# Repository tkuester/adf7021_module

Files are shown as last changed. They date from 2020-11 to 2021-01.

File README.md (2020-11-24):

# ADF7021 Module

Per a discussion with SP5WWP, it would be advantageous to the M17 project to
have a breakout board that can be uesd to prototype with the AD7021 module.
While Analog provides a reasonably priced development module, it is difficult
to modify, and doesn't integrate well into other projects.

Given this, the module should be...

 - Hackable
   - Easy to use as a standalone board (ie: 0.1" headers)
   - Assemble with hobbyist level equipment
   - Financially accessable, limit difficult to source parts
 - Modular
   - Minimize commitments like filter topology / amplifier output
     - Can use as TX, RX, or TX/RX (two SMA conns)
   - Optional footprints to allow for various configurations
 - Designed to integrate into later projects
   - RF shileding footprint
   - Mounting holes, pluggable connectors, etc
 - Not designed for the TR-9
   - Suspect TR-9 needs tighter integration
   - Would be nice, but requirements seem to conflict

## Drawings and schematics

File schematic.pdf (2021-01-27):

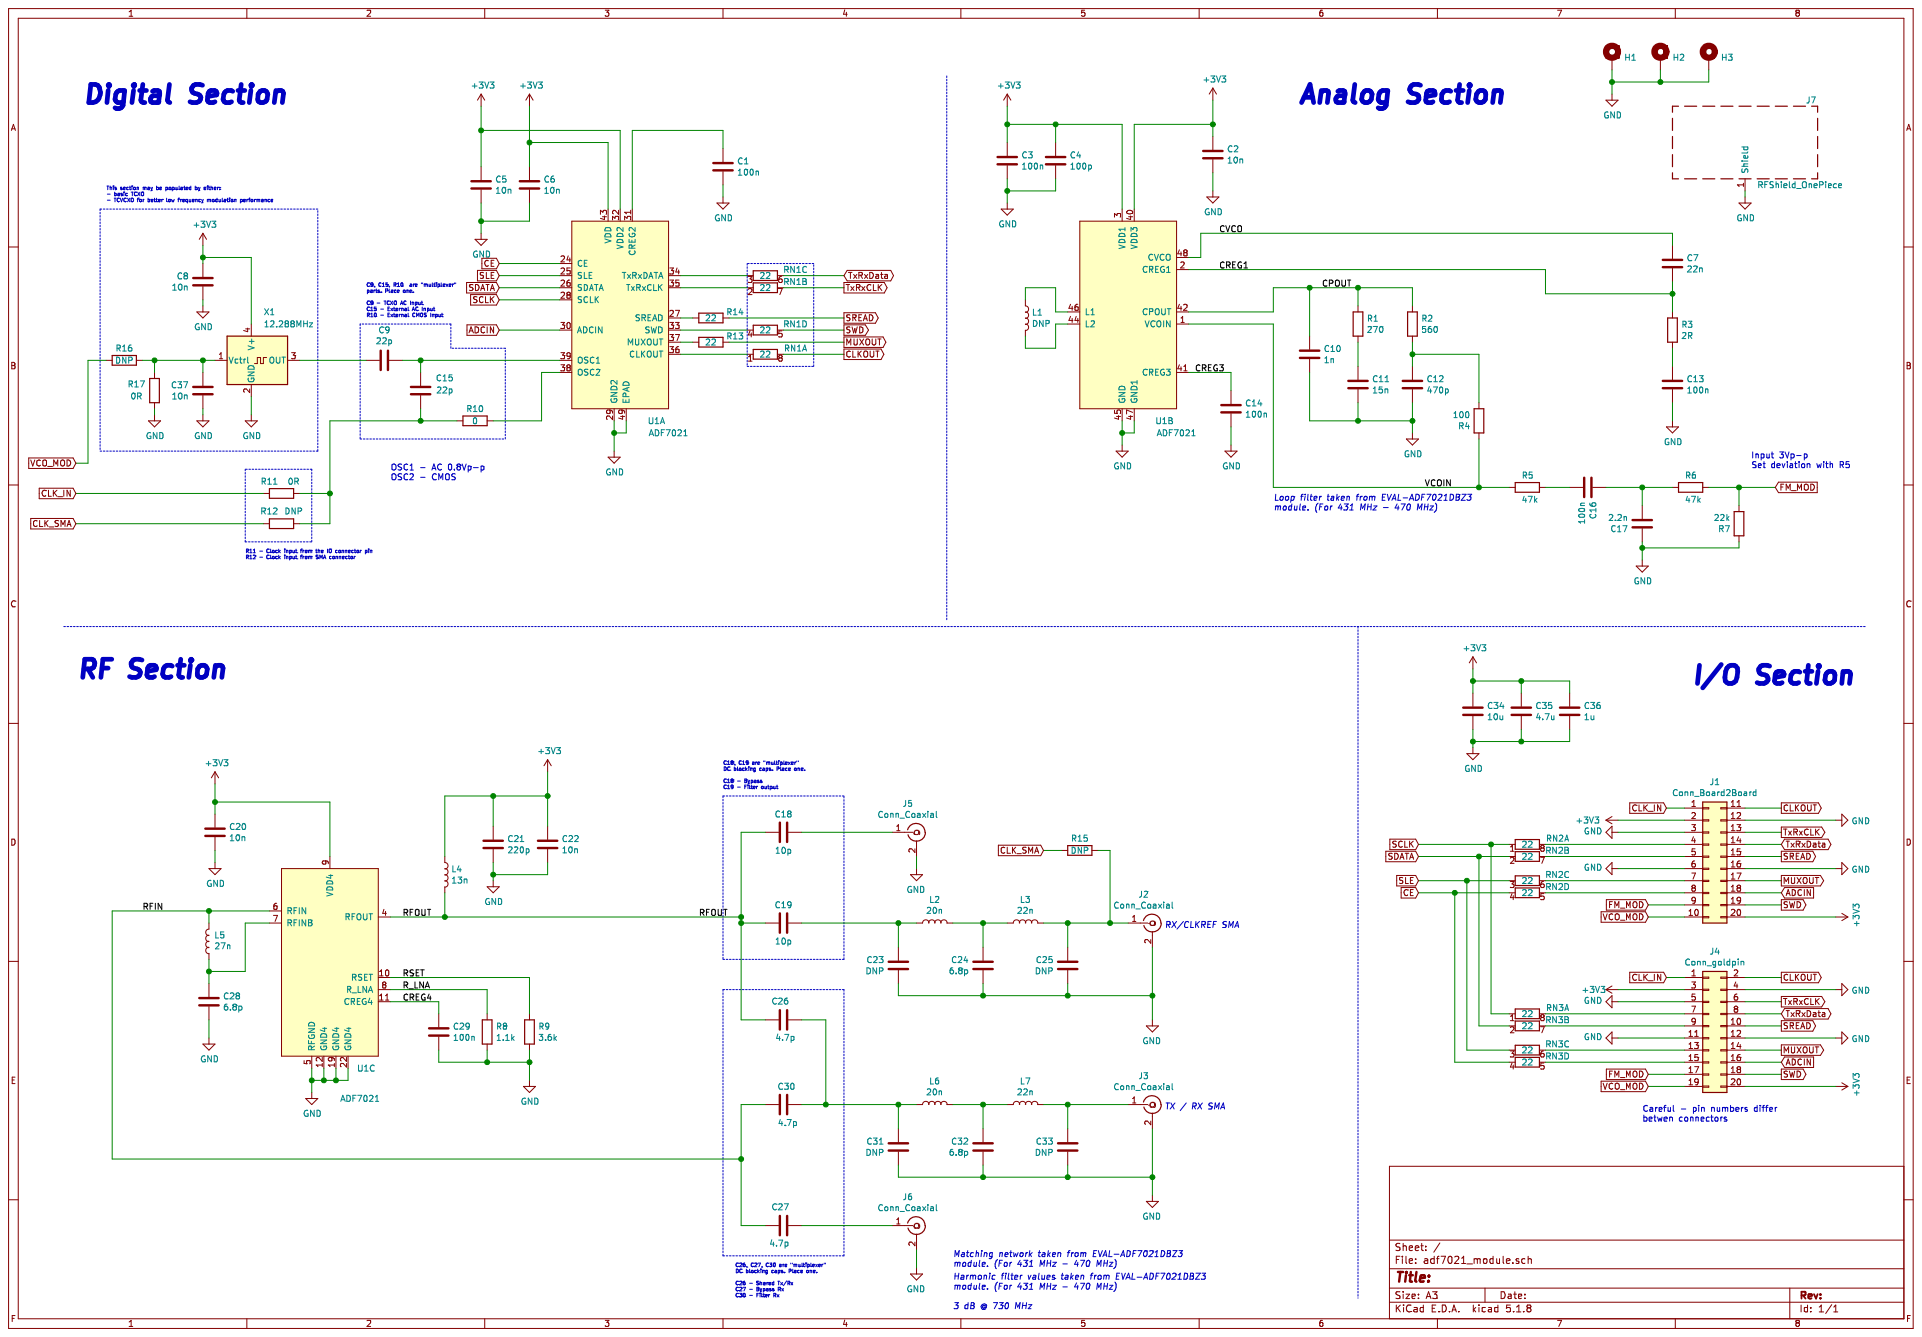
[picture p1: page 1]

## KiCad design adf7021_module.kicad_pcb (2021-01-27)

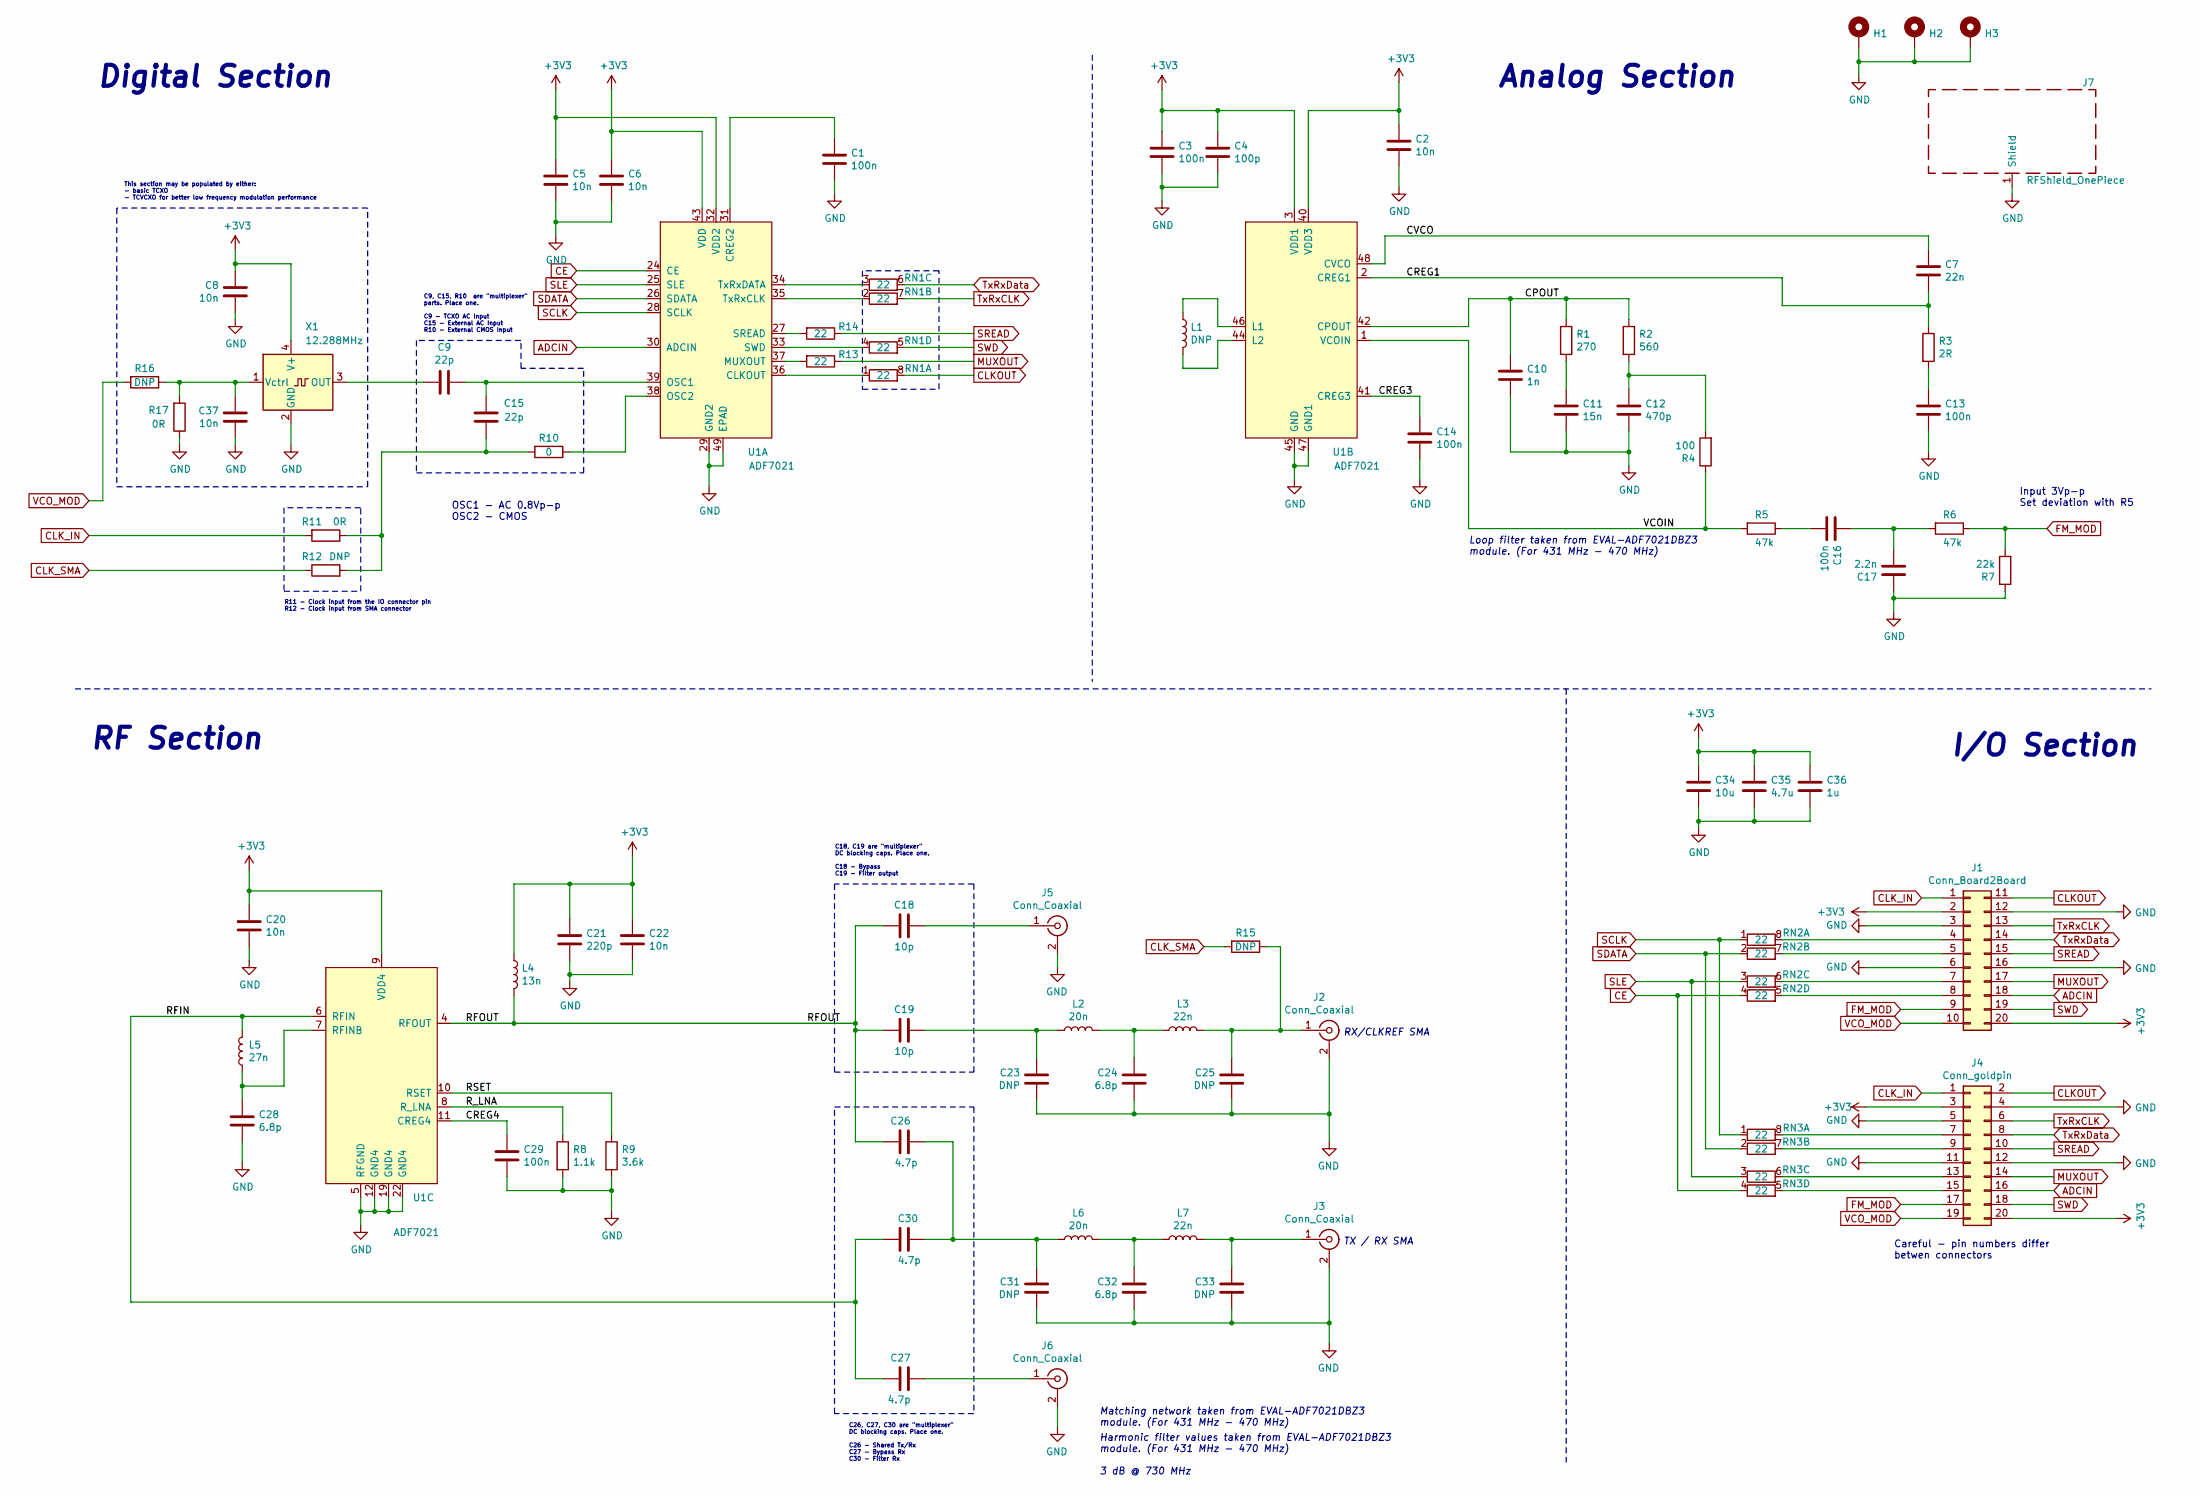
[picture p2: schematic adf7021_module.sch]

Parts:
C1, C3, C13, C14, C16, C29: 100n; C_0402_1005Metric_Pad0.74x0.62mm_HandSolder
C2, C5, C6, C8, C20, C22, C37: 10n; C_0402_1005Metric_Pad0.74x0.62mm_HandSolder
C4: 100p; C_0402_1005Metric_Pad0.74x0.62mm_HandSolder
C7: 22n; C_0402_1005Metric_Pad0.74x0.62mm_HandSolder
C9, C15: 22p; C_0402_1005Metric_Pad0.74x0.62mm_HandSolder
C10: 1n; C_0402_1005Metric_Pad0.74x0.62mm_HandSolder
C11: 15n; C_0402_1005Metric_Pad0.74x0.62mm_HandSolder
C12: 470p; C_0402_1005Metric_Pad0.74x0.62mm_HandSolder
C17: 2.2n; C_0402_1005Metric_Pad0.74x0.62mm_HandSolder
C18, C19: 10p; C_0402_1005Metric_Pad0.74x0.62mm_HandSolder
C21: 220p; C_0402_1005Metric_Pad0.74x0.62mm_HandSolder
C23, C25, C31, C33: DNP; C_0402_1005Metric_Pad0.74x0.62mm_HandSolder
C24, C28, C32: 6.8p; C_0402_1005Metric_Pad0.74x0.62mm_HandSolder
C26, C27, C30: 4.7p; C_0402_1005Metric_Pad0.74x0.62mm_HandSolder
C34: 10u; C_0603_1608Metric_Pad1.08x0.95mm_HandSolder
C35: 4.7u; C_0603_1608Metric_Pad1.08x0.95mm_HandSolder
C36: 1u; C_0603_1608Metric_Pad1.08x0.95mm_HandSolder
H1, H2, H3: MountingHole_Pad; MountingHole_2.2mm_M2_Pad_TopBottom
J1: Conn_Board2Board; Hirose_DF12_DF12E3.0-20DP-0.5V_2x10_P0.50mm_Vertical
J2, J3: Conn_Coaxial; SMA_Molex_73251-2200_Horizontal
J4: Conn_goldpin; PinSocket_2x10_P2.54mm_Vertical
J5, J6: Conn_Coaxial; U.FL_Hirose_U.FL-R-SMT-1_Vertical
J7: RFShield_OnePiece; Laird_Technologies_BMI-S-205-F_38.10x25.40mm
L1: DNP; L_0402_1005Metric_Pad0.77x0.64mm_HandSolder
L2, L6: 20n; L_0402_1005Metric_Pad0.77x0.64mm_HandSolder
L3, L7: 22n; L_0402_1005Metric_Pad0.77x0.64mm_HandSolder
L4: 13n; L_0402_1005Metric_Pad0.77x0.64mm_HandSolder
L5: 27n; L_0402_1005Metric_Pad0.77x0.64mm_HandSolder
R1: 270; R_0402_1005Metric_Pad0.72x0.64mm_HandSolder
R2: 560; R_0402_1005Metric_Pad0.72x0.64mm_HandSolder
R3: 2R; R_0402_1005Metric_Pad0.72x0.64mm_HandSolder
R4: 100; R_0402_1005Metric_Pad0.72x0.64mm_HandSolder
R5, R6: 47k; R_0402_1005Metric_Pad0.72x0.64mm_HandSolder
R7: 22k; R_0402_1005Metric_Pad0.72x0.64mm_HandSolder
R8: 1.1k; R_0402_1005Metric_Pad0.72x0.64mm_HandSolder
R9: 3.6k; R_0402_1005Metric_Pad0.72x0.64mm_HandSolder
R10: 0; R_0402_1005Metric_Pad0.72x0.64mm_HandSolder
R11, R17: 0R; R_0402_1005Metric_Pad0.72x0.64mm_HandSolder
R12, R15, R16: DNP; R_0402_1005Metric_Pad0.72x0.64mm_HandSolder
R13, R14: 22; R_0402_1005Metric_Pad0.72x0.64mm_HandSolder
RN1, RN2, RN3: 22; R_Array_Concave_4x0402
U1: ADF7021; QFN-48-1EP_7x7mm_P0.5mm_EP5.3x5.3mm
X1: 12.288MHz; Oscillator_SMD_EuroQuartz_XO32-4Pin_3.2x2.5mm_HandSoldering

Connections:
+3V3: C2.1, C3.1, C4.1, C5.1, C6.1, C8.1, C20.1, C21.1, C22.1, C34.1, C35.1, C36.1, J1.2, J1.20, J4.3, J4.20, L4.1, U1.3 (VDD1), U1.9 (VDD4), U1.32 (VDD2), U1.40 (VDD3), U1.43 (VDD), X1.4 (V+)
/CPOUT: C10.1, R1.1, R2.1, U1.42 (CPOUT)
/CREG1: C7.2, R3.1, U1.2 (CREG1)
/CREG3: C14.1, U1.41 (CREG3)
/CREG4: C29.1, U1.11 (CREG4)
/CVCO: C7.1, U1.48 (CVCO)
/RFIN: C27.1, C30.2, L5.2, U1.6 (RFIN)
/RFOUT: C18.2, C19.2, C26.1, L4.2, U1.4 (RFOUT)
/RSET: R9.1, U1.10 (RSET)
/R_LNA: R8.1, U1.8 (R_LNA)
/VCOIN: R4.1, R5.2, U1.1 (VCOIN)
ADCIN: J1.18, J4.16, U1.30 (ADCIN)
CE: RN2.4 (R4.1), RN3.4 (R4.1), U1.24 (CE)
CLKOUT: J1.11, J4.2, RN1.8 (R1.2)
CLK_IN: J1.1, J4.1, R11.2
CLK_SMA: R12.1, R15.2
FM_MOD: J1.9, J4.17, R6.1, R7.2
GND: C1.2, C2.2, C3.2, C4.2, C5.2, C6.2, C8.2, C10.2, C11.2, C12.2, C13.2, C14.2, C17.1, C20.2, C21.2, C22.2, C23.2, C24.2, C25.2, C28.2, C29.2, C31.2, C32.2, C33.2, C34.2, C35.2, C36.2, C37.2, H1.1, H2.1, H3.1, J1.3, J1.6, J1.12, J1.16, J2.2 (Ext), J3.2 (Ext), J4.4, J4.5, J4.11, J4.12, J5.2 (Ext), J6.2 (Ext), J7.1, R7.1, R8.2, R9.2, R17.1, U1.5 (RFGND), U1.12 (GND4), U1.19 (GND4), U1.22 (GND4), U1.29 (GND2), U1.45 (GND), U1.47 (GND1), U1.49 (EPAD), X1.2 (GND)
MUXOUT: J1.17, J4.14, R13.1
unnamed: C1.1, U1.31 (CREG2)
unnamed: C9.2, X1.3 (OUT)
unnamed: C11.1, R1.2
unnamed: C12.1, R2.2, R4.2
unnamed: C13.1, R3.2
unnamed: C15.1, R10.2, R11.1, R12.2
unnamed: C9.1, C15.2, U1.39 (OSC1)
unnamed: C16.1, C17.2, R6.2
unnamed: C16.2, R5.1
unnamed: C18.1, J5.1 (In)
unnamed: C19.1, C23.1, L2.2
unnamed: C24.1, L2.1, L3.2
unnamed: C25.1, J2.1 (In), L3.1, R15.1
unnamed: C26.2, C30.1, C31.1, L6.2
unnamed: C27.2, J6.1 (In)
unnamed: C28.1, L5.1, U1.7 (RFINB)
unnamed: C32.1, L6.1, L7.2
unnamed: C33.1, J3.1 (In), L7.1
unnamed: C37.1, R16.1, R17.2, X1.1 (Vctrl)
unnamed: J1.4, RN2.8 (R1.2)
unnamed: J1.5, RN2.7 (R2.2)
unnamed: J1.7, RN2.6 (R3.2)
unnamed: J1.8, RN2.5 (R4.2)
unnamed: J4.7, RN3.8 (R1.2)
unnamed: J4.9, RN3.7 (R2.2)
unnamed: J4.13, RN3.6 (R3.2)
unnamed: J4.15, RN3.5 (R4.2)
unnamed: L1.1, U1.46 (L1)
unnamed: L1.2, U1.44 (L2)
unnamed: R10.1, U1.38 (OSC2)
unnamed: R13.2, U1.37 (MUXOUT)
unnamed: R14.2, U1.27 (SREAD)
unnamed: RN1.1 (R1.1), U1.36 (CLKOUT)
unnamed: RN1.2 (R2.1), U1.35 (TxRxCLK)
unnamed: RN1.3 (R3.1), U1.34 (TxRxDATA)
unnamed: RN1.4 (R4.1), U1.33 (SWD)
SCLK: RN2.1 (R1.1), RN3.1 (R1.1), U1.28 (SCLK)
SDATA: RN2.2 (R2.1), RN3.2 (R2.1), U1.26 (SDATA)
SLE: RN2.3 (R3.1), RN3.3 (R3.1), U1.25 (SLE)
SREAD: J1.15, J4.10, R14.1
SWD: J1.19, J4.18, RN1.5 (R4.2)
TxRxCLK: J1.13, J4.6, RN1.7 (R2.2)
TxRxData: J1.14, J4.8, RN1.6 (R3.2)
VCO_MOD: J1.10, J4.19, R16.2

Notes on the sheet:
Digital Section
Analog Section
Loop filter taken from EVAL-ADF7021DBZ3 module. (For 431 MHz - 470 MHz)
Matching network taken from EVAL-ADF7021DBZ3 module. (For 431 MHz - 470 MHz)
OSC1 - AC 0.8Vp-p OSC2 - CMOS
Input 3Vp-p Set deviation with R5
C26, C27, C30 are "multiplexer" DC blocking caps. Place one. C26 - Shared Tx/Rx C27 - Bypass Rx C30 - Filter Rx
C18, C19 are "multiplexer" DC blocking caps. Place one. C18 - Bypass C19 - Filter output
C9, C15, R10 are "multiplexer" parts. Place one. C9 - TCXO AC Input C15 - External AC Input R10 - External CMOS Input
I/O Section
Harmonic filter values taken from EVAL-ADF7021DBZ3 module. (For 431 MHz - 470 MHz) 3 dB @ 730 MHz
TX / RX SMA
RX/CLKREF SMA
Careful - pin numbers differ betwen connectors
RF Section
R11 - Clock input from the IO connector pin R12 - Clock input from SMA connector
This section may be populated by either: - basic TCXO - TCVCXO for better low frequency modulation performance

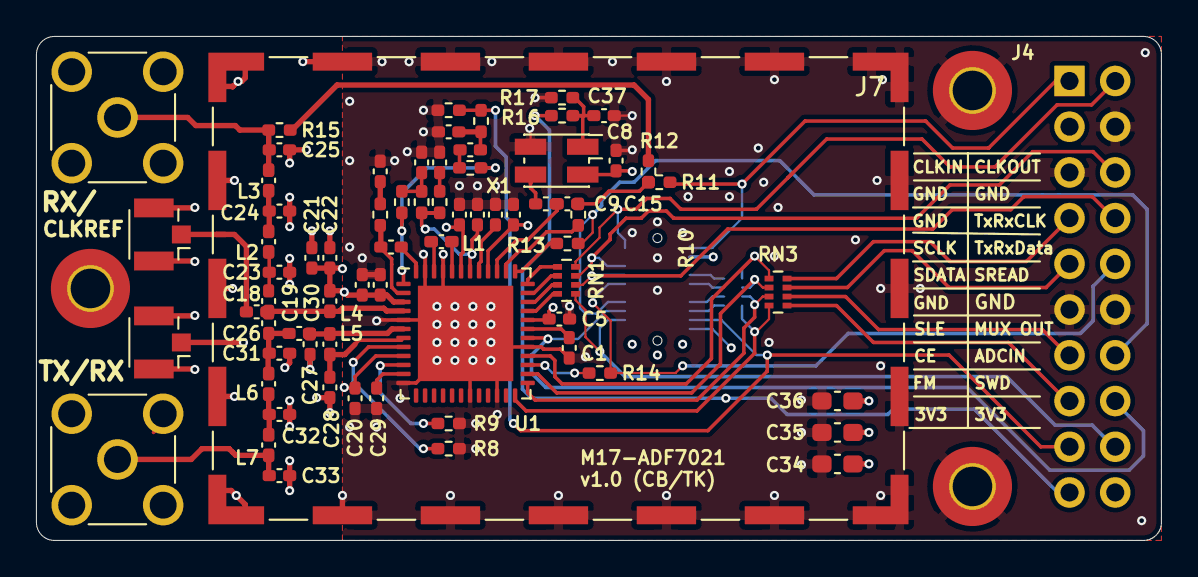
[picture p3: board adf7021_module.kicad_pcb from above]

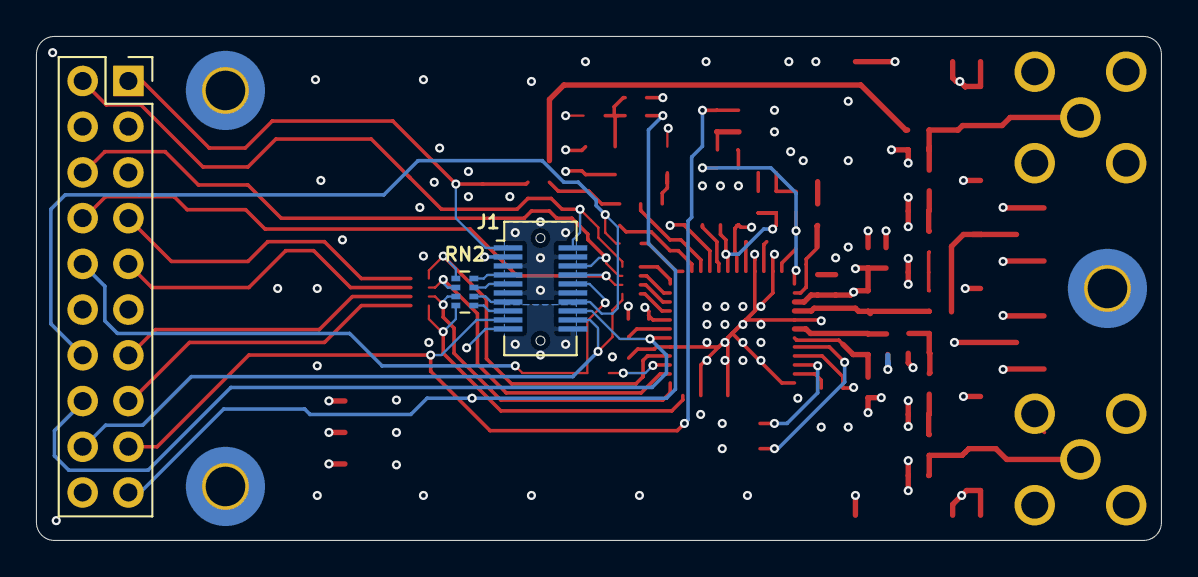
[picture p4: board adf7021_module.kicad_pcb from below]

Board: 4 copper layers, 62.5 x 28.0 mm, 76 parts (3 on the bottom side), 63 nets.

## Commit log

2020-11-20 Initial commit of schematic
    [adf7021_module.sch]
2020-12-05 Add external clock input SMA
    [adf7021_module.sch]
2020-12-05 RF output chain, labels for digital pins
    [adf7021_module.sch]
2020-12-05 Improving documentation on schematic
    [adf7021_module.sch]
2020-12-05 Adding 2x10 data headers, unifying CLK_IN signal
    [adf7021_module.sch]
2020-12-05 Annotating parts
    [adf7021_module.sch]
2020-12-05 Adding series resistors on clock / data pins
    [adf7021_module.sch]
2020-12-05 Tidying up organization of FM Mod section
    [adf7021_module.sch]
2020-12-05 Adding mounting holes
    [adf7021_module.sch]
2020-12-05 Adding bus resistors on all inputs / outputs
    You get a bus resistor! You get a bus resistor!
    EVERYONE GETS A BUS RESISTOOOOORRR!!1
    [adf7021_module.sch]
2020-12-07 rough component placement, stackup definition
    [adf7021_module.kicad_pcb, adf7021_module.sch]
2020-12-09 some component placement attempts
    [adf7021_module.kicad_pcb]
2020-12-13 some more layout attempts
    [adf7021_module.kicad_pcb, adf7021_module.sch]
2020-12-13 Rounding corners of PCB
    [adf7021_module.kicad_pcb]
2020-12-13 Adding mechanical dimensions, adjusting location of J1
    [adf7021_module.kicad_pcb]
2020-12-13 Giving SMA's more generous spacing from edge
    [adf7021_module.kicad_pcb]
2020-12-13 Adding 3V3/GND planes to internal layers
    [adf7021_module.kicad_pcb]
2020-12-13 Shrinking vias to OSH Park spec (10 mil drill, 20 mil dia)
    This is larger than JLCPCB's spec. Additionally, while OSH Park can
    technically handle 18 mil dia, that results in 4 mil annular rings,
    which may push the PCB tech a little too far. (Minimum trace/space is
    5 mil.)
    [adf7021_module.kicad_pcb]
2020-12-13 Fixing pin that was off-grid
    [adf7021_module.sch]
2020-12-13 Routing WIP
    * Trying for symmetrical filter layout
    * Moving non-essential circuitry (ie: FM_MOD filter) away from U1
    * GND pad for J1 on bottom
    * Trying to have SMD orientation match schematic (ie: L5/C28)
    [adf7021_module.kicad_pcb]
2020-12-13 RF bypass will use auxillary U.FL instead of SMA
    This greatly reduces schematic complexity. Since this is more of a
    "debug" feature that we do not anticipate using much, it seems ok to
    make this a secondary connector.
    [adf7021_module.sch]
2020-12-13 Swapping ADCIN and SWD for routing sanity
    [adf7021_module.sch]
2020-12-13 Most traces routed, except debug U.FL's
    * Care to prevent plane slots on In1/In2 w/ vias
    [adf7021_module.kicad_pcb]
2020-12-13 Adding pinout silkscreen
    [adf7021_module.kicad_pcb]
2020-12-13 Moving mounting holes to make room for U.FL's
    * 0 unrouted traces
    * DRC clear
    [adf7021_module.kicad_pcb]
2020-12-13 Hiding silk screen that won't fit
    [adf7021_module.kicad_pcb]
2020-12-13 Preliminary via stitching
    [adf7021_module.kicad_pcb]
2020-12-13 Version silkscreen, via stitching under U1
    [adf7021_module.kicad_pcb]
2021-01-02 adding shield, moving uFL debug connectors, adding optional SMA clock source input
    [adf7021_module.kicad_pcb, adf7021_module.sch]
2021-01-02 adding PDF schematic
2021-01-10 adding VFO pin
    [adf7021_module.kicad_pcb, adf7021_module.sch]
2021-01-27 adding fab outputs
    [adf7021_module.kicad_pcb, adf7021_module.sch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]
